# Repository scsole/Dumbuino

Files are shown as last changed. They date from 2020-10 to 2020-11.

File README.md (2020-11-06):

# Dumbuino

A basic Arduino with two 10A 48V DC switches controlled using digital outputs.

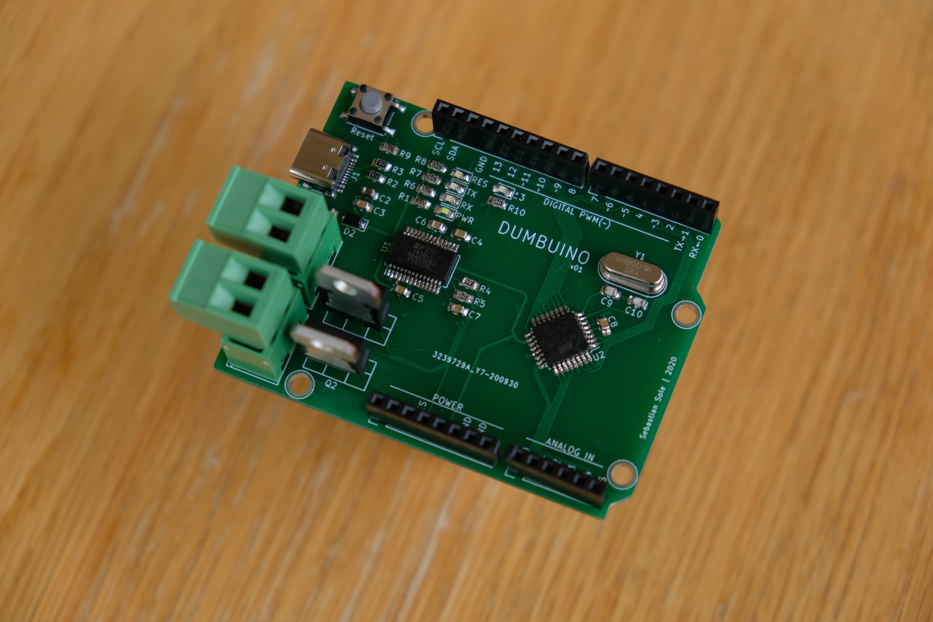
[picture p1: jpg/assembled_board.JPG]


## Specs

| | |
--- | ---
Microcontroller             | ATmega328P
Operating Voltage           | 5V
USB Port                    | USB 2.0 Type-C
10A 48V DC Switches         | 2 (shared with digital pins 9 & 10)
Digital I/O Pins            | 14 (of which 6 provide PWM output)
PWM Digital I/O Pins        | 6
Analog Input Pins           | 6
DC Current per I/O Pin      | 20 mA
DC Current for 3.3V Pin     | 50 mA
Flash Memory                | 32 KB (ATmega328P) of which 0.5 KB used by bootloader
SRAM                        | 2 KB (ATmega328P)
EEPROM                      | 1 KB (ATmega328P)
Clock Speed                 | 16 MHz
LED_BUILTIN                 | 13

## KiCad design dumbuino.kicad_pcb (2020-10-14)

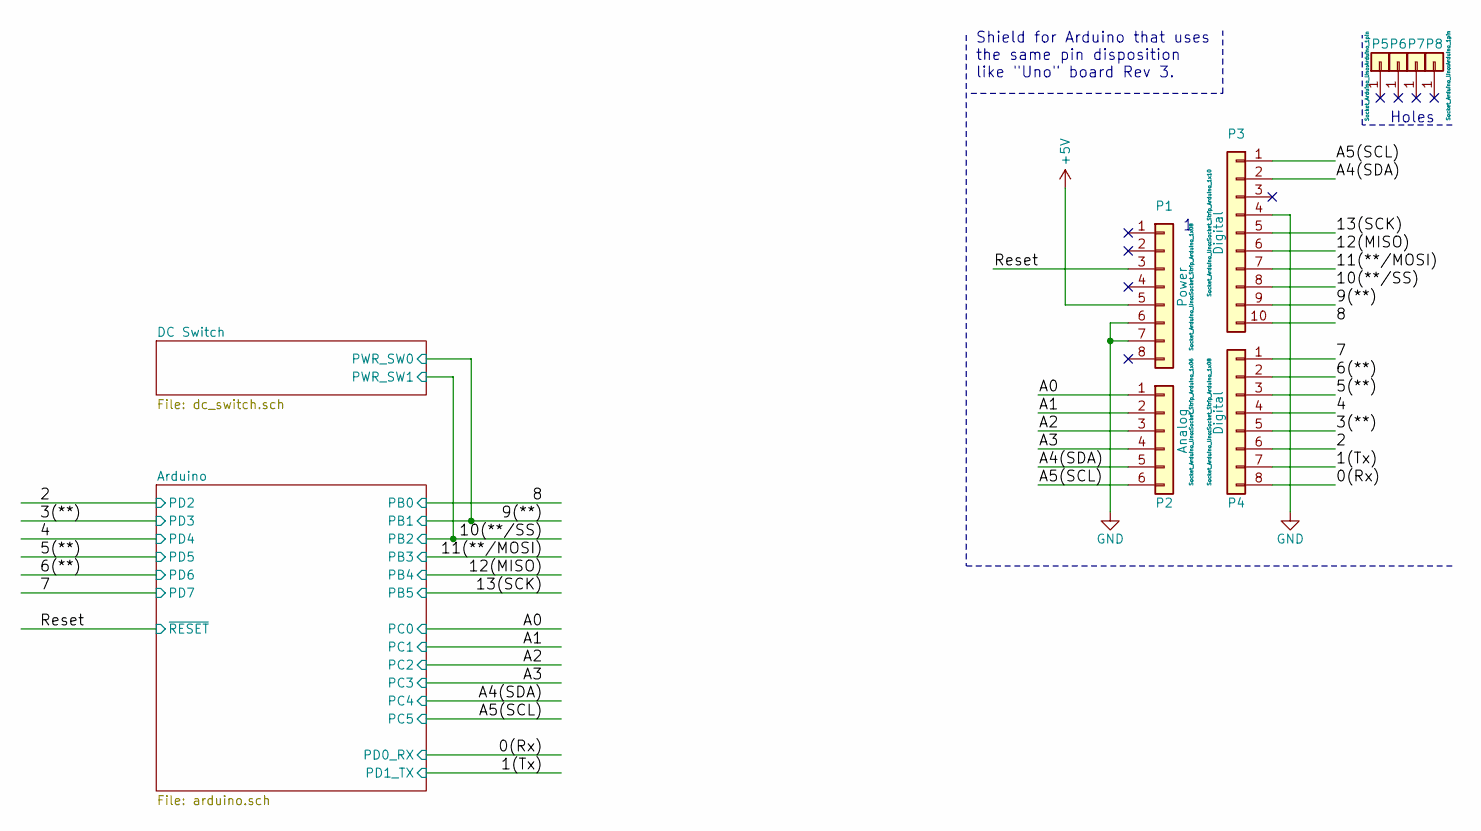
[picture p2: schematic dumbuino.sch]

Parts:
P1: Power; Socket_Strip_Arduino_1x08
P2: Analog; Socket_Strip_Arduino_1x06
P3: Digital; Socket_Strip_Arduino_1x10
P4: Digital; Socket_Strip_Arduino_1x08
P5, P6, P7, P8: CONN_01X01; Arduino_1pin

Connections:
+5V: P1.5; also elsewhere on the board
/0(Rx): P4.8; also elsewhere on the board
/1(Tx): P4.7; also elsewhere on the board
/2: P4.6; also elsewhere on the board
/3(**): P4.5; also elsewhere on the board
/4: P4.4; also elsewhere on the board
/5(**): P4.3; also elsewhere on the board
/6(**): P4.2; also elsewhere on the board
/7: P4.1; also elsewhere on the board
/8: P3.10; also elsewhere on the board
/9(**): P3.9; also elsewhere on the board
/10(**/SS): P3.8; also elsewhere on the board
/11(**/MOSI): P3.7; also elsewhere on the board
/12(MISO): P3.6; also elsewhere on the board
/13(SCK): P3.5; also elsewhere on the board
/A0: P2.1; also elsewhere on the board
/A1: P2.2; also elsewhere on the board
/A2: P2.3; also elsewhere on the board
/A3: P2.4; also elsewhere on the board
/A4(SDA): P2.5, P3.2; also elsewhere on the board
/A5(SCL): P2.6, P3.1; also elsewhere on the board
/Reset: P1.3; also elsewhere on the board
GND: P1.6, P1.7, P3.4; also elsewhere on the board

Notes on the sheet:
Holes
Shield for Arduino that uses the same pin disposition like "Uno" board Rev 3.

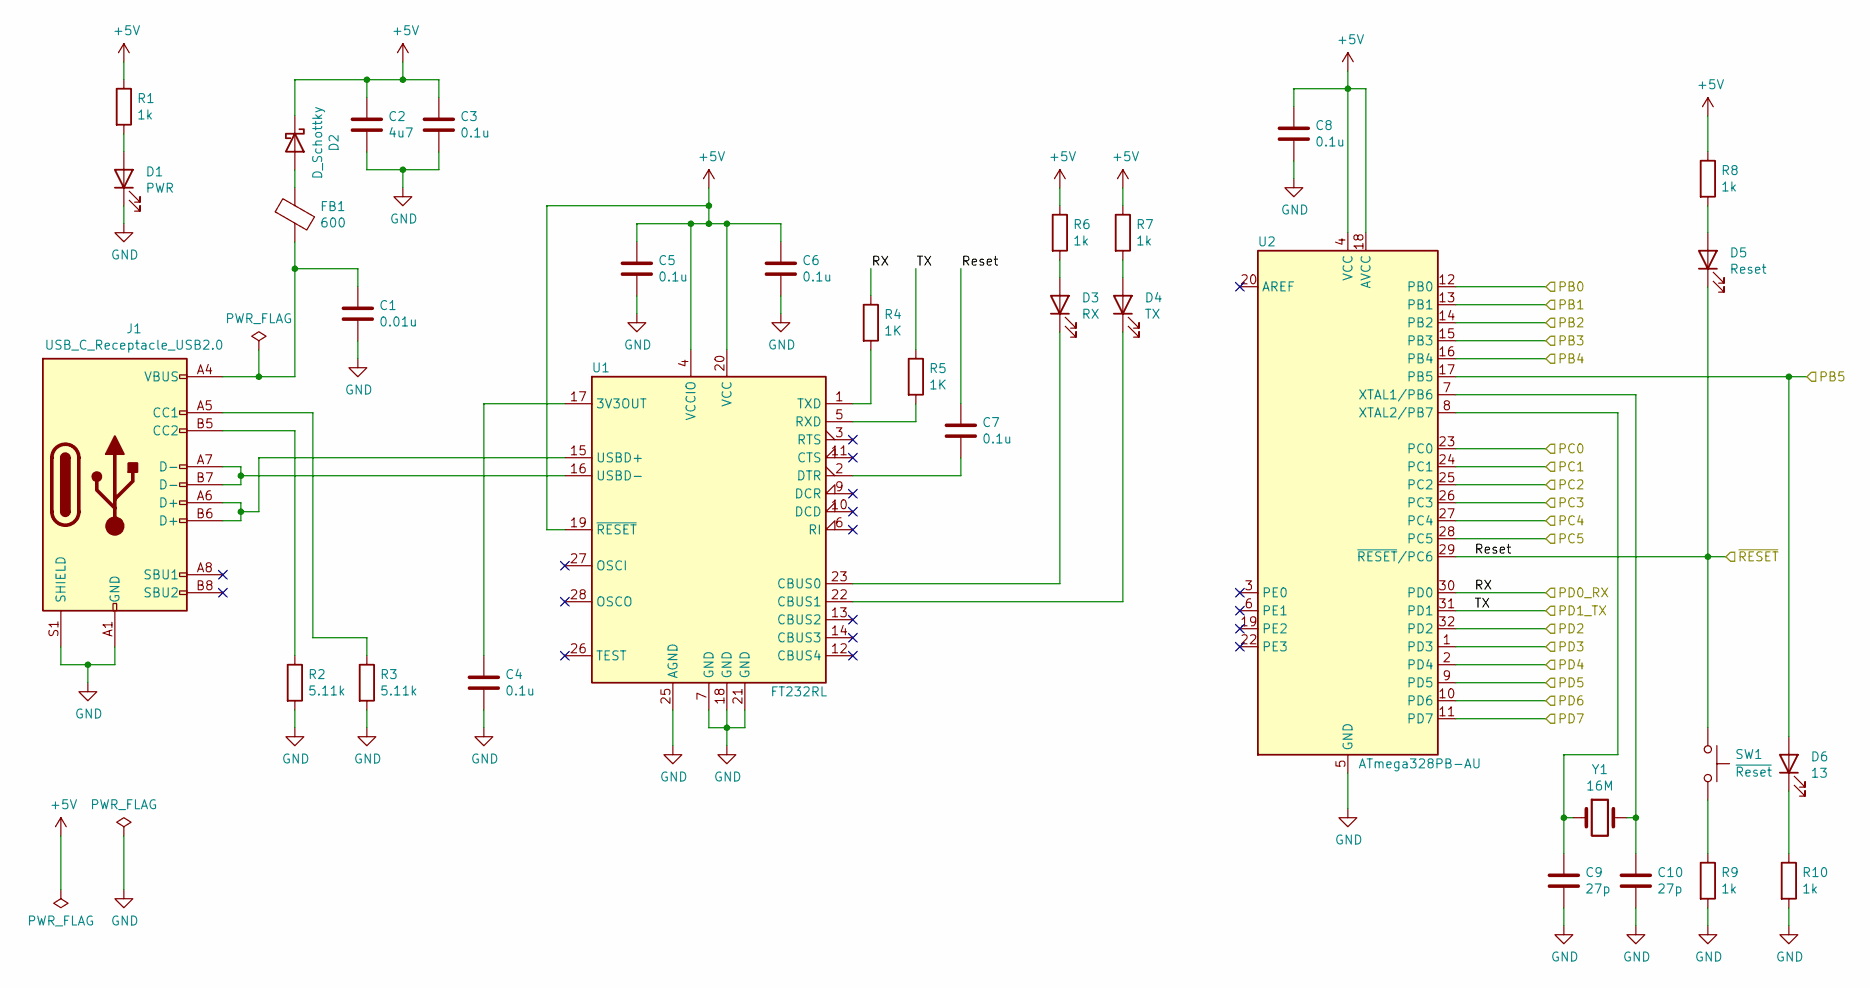
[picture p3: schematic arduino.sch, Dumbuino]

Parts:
C1: 0.01u; C_0805_2012Metric_Pad1.15x1.40mm_HandSolder
C2: 4u7; C_0805_2012Metric_Pad1.15x1.40mm_HandSolder
C3, C4, C5, C6, C7, C8: 0.1u; C_0805_2012Metric_Pad1.15x1.40mm_HandSolder
C9, C10: 27p; C_0805_2012Metric_Pad1.15x1.40mm_HandSolder
D1: PWR; LED_0805_2012Metric_Pad1.15x1.40mm_HandSolder
D2: D_Schottky; D_SOD-123F
D3: RX; LED_0805_2012Metric_Pad1.15x1.40mm_HandSolder
D4: TX; LED_0805_2012Metric_Pad1.15x1.40mm_HandSolder
D5: Reset; LED_0805_2012Metric_Pad1.15x1.40mm_HandSolder
D6: 13; LED_0805_2012Metric_Pad1.15x1.40mm_HandSolder
FB1: 600; L_0805_2012Metric_Pad1.15x1.40mm_HandSolder
J1: USB_C_Receptacle_USB2.0; USB_C_Receptacle_HRO_TYPE-C-31-M-12
R1, R6, R7, R8, R9, R10: 1k; R_0805_2012Metric_Pad1.15x1.40mm_HandSolder
R2, R3: 5.11k; R_0805_2012Metric_Pad1.15x1.40mm_HandSolder
R4, R5: 1K; R_0805_2012Metric_Pad1.15x1.40mm_HandSolder
SW1: ~Reset; SW_SPST_PTS645
U1: FT232RL; SSOP-28_5.3x10.2mm_P0.65mm
U2: ATmega328PB-AU; TQFP-32_7x7mm_P0.8mm
Y1: 16M; Crystal_HC49-U_Vertical

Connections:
+5V: C2.1, C3.1, C5.1, C6.1, C8.1, D2.1 (K), R1.1, R6.1, R7.1, R8.1, U1.4 (VCCIO), U1.19 (~RESET~), U1.20 (VCC), U2.4 (VCC), U2.18 (AVCC); also elsewhere on the board
/0(Rx): R4.1, U2.30 (PD0); also elsewhere on the board
/1(Tx): R5.1, U2.31 (PD1); also elsewhere on the board
/2: U2.32 (PD2); also elsewhere on the board
/3(**): U2.1 (PD3); also elsewhere on the board
/4: U2.2 (PD4); also elsewhere on the board
/5(**): U2.9 (PD5); also elsewhere on the board
/6(**): U2.10 (PD6); also elsewhere on the board
/7: U2.11 (PD7); also elsewhere on the board
/8: U2.12 (PB0); also elsewhere on the board
/9(**): U2.13 (PB1); also elsewhere on the board
/10(**/SS): U2.14 (PB2); also elsewhere on the board
/11(**/MOSI): U2.15 (PB3); also elsewhere on the board
/12(MISO): U2.16 (PB4); also elsewhere on the board
/13(SCK): D6.2 (A), U2.17 (PB5); also elsewhere on the board
/A0: U2.23 (PC0); also elsewhere on the board
/A1: U2.24 (PC1); also elsewhere on the board
/A2: U2.25 (PC2); also elsewhere on the board
/A3: U2.26 (PC3); also elsewhere on the board
/A4(SDA): U2.27 (PC4); also elsewhere on the board
/A5(SCL): U2.28 (PC5); also elsewhere on the board
/Reset: C7.2, D5.1 (K), SW1.1, U2.29 (~RESET~/PC6); also elsewhere on the board
GND: C1.2, C2.2, C3.2, C4.2, C5.2, C6.2, C8.2, C9.2, C10.2, D1.1 (K), J1.A1 (GND), J1.A12 (GND), J1.B1 (GND), J1.B12 (GND), J1.S1 (SHIELD), R2.2, R3.2, R9.2, R10.2, U1.7 (GND), U1.18 (GND), U1.21 (GND), U1.25 (AGND), U2.5 (GND), U2.21 (GND); also elsewhere on the board
unnamed: C1.1, FB1.2, J1.A4 (VBUS), J1.A9 (VBUS), J1.B4 (VBUS), J1.B9 (VBUS)
unnamed: C4.1, U1.17 (3V3OUT)
unnamed: C7.1, U1.2 (DTR)
unnamed: C9.1, U2.8 (XTAL2/PB7), Y1.1
unnamed: C10.1, U2.7 (XTAL1/PB6), Y1.2
unnamed: D1.2 (A), R1.2
unnamed: D2.2 (A), FB1.1
unnamed: D3.1 (K), U1.23 (CBUS0)
unnamed: D3.2 (A), R6.2
unnamed: D4.1 (K), U1.22 (CBUS1)
unnamed: D4.2 (A), R7.2
unnamed: D5.2 (A), R8.2
unnamed: D6.1 (K), R10.1
unnamed: J1.A5 (CC1), R3.1
unnamed: J1.A6 (D+), J1.B6 (D+), U1.15 (USBD+)
unnamed: J1.A7 (D-), J1.B7 (D-), U1.16 (USBD-)
unnamed: J1.B5 (CC2), R2.1
unnamed: R4.2, U1.1 (TXD)
unnamed: R5.2, U1.5 (RXD)
unnamed: R9.1, SW1.2

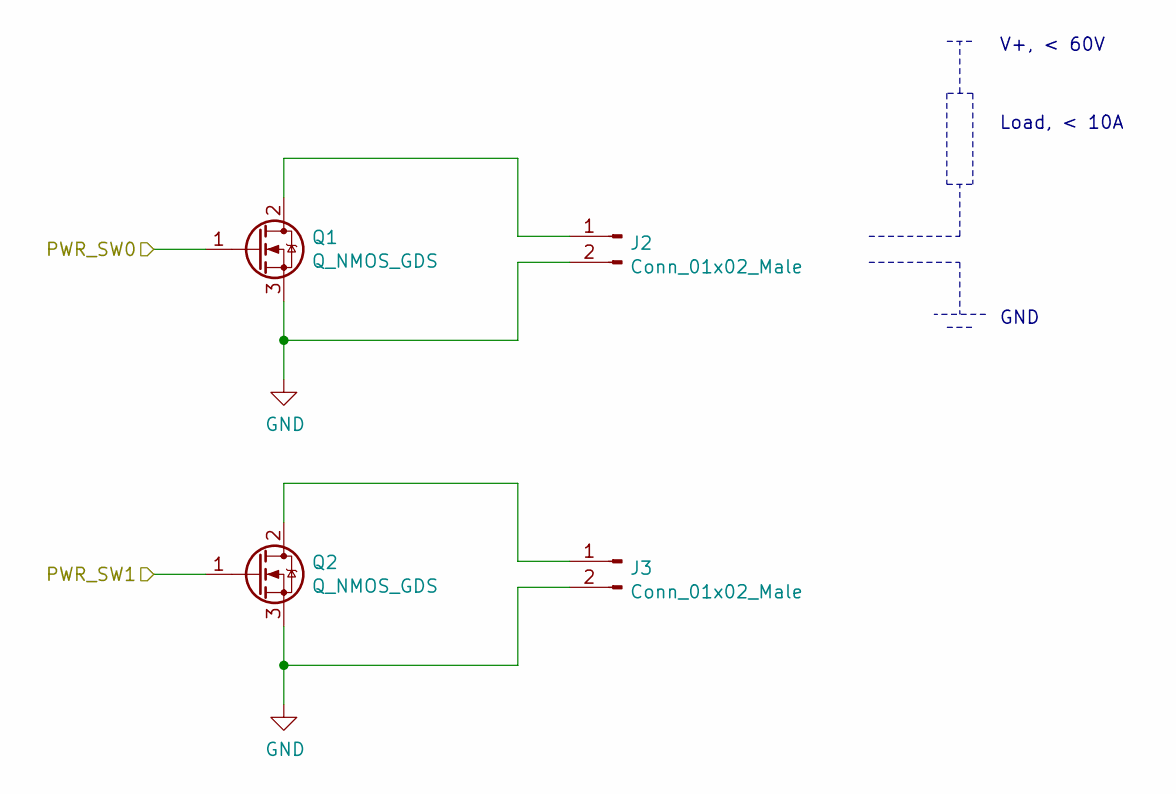
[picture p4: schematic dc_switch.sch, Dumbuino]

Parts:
J2, J3: Conn_01x02_Male; PhoenixContact_MSTBVA_2,5_2-G-5,08_1x02_P5.08mm_Vertical
Q1, Q2: Q_NMOS_GDS; TO-220F-3_Vertical

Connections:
/9(**): Q1.1 (G); also elsewhere on the board
/10(**/SS): Q2.1 (G); also elsewhere on the board
GND: J2.2, J3.2, Q1.3 (S), Q2.3 (S); also elsewhere on the board
unnamed: J2.1, Q1.2 (D)
unnamed: J3.1, Q2.2 (D)

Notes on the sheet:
GND
Load, < 10A
V+, < 60V

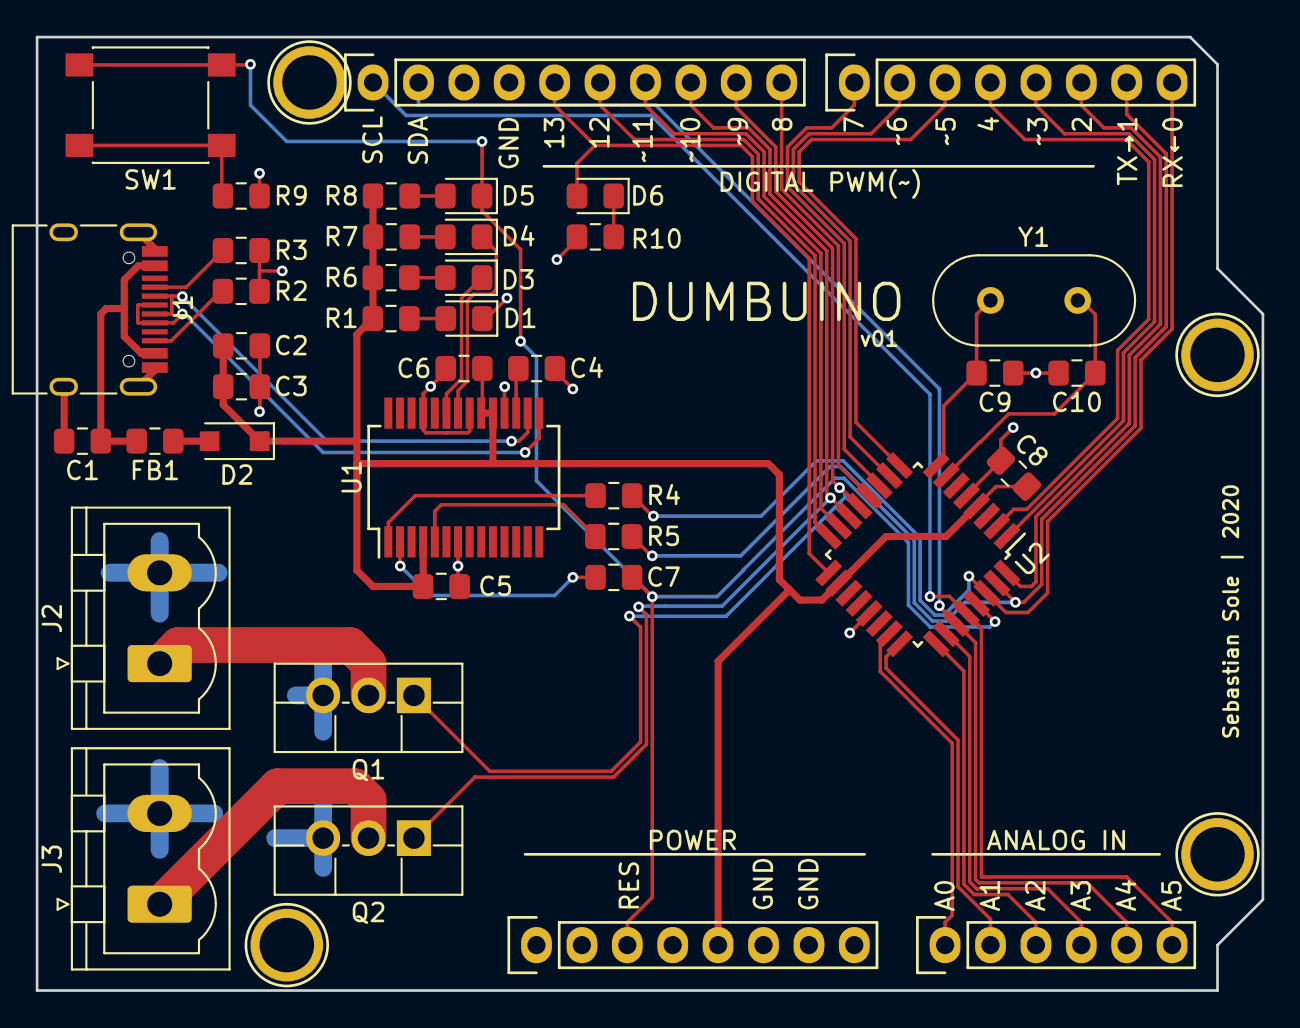
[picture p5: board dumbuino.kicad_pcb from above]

Board: 4 copper layers, 68.6 x 53.3 mm, 44 parts (0 on the bottom side), 45 nets.

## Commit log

2020-09-20 Initial template files
    [dumbuino.kicad_pcb, dumbuino.sch]
2020-09-20 Added arduino schematic
    [arduino.sch, dumbuino.sch]
2020-09-20 Added two 48V digital outputs
    [arduino.sch, dc_switch.sch, dumbuino.sch]
2020-09-20 Associated footprints
    [arduino.sch, dc_switch.sch]
2020-09-20 Defined board properties
    [dumbuino.kicad_pcb]
2020-09-20 Initial component placement
    [dumbuino.kicad_pcb]
2020-09-20 Finished initial board layout
    [dumbuino.kicad_pcb]
2020-09-20 Adjusted tracks
    [dumbuino.kicad_pcb]
2020-09-20 Updated F.SilkS
    [dumbuino.kicad_pcb]
2020-09-23 Update track width
    [dumbuino.kicad_pcb]
2020-09-23 Generated gerbers
    [dumbuino-B_Cu.gbr, dumbuino-B_Mask.gbr, dumbuino-B_SilkS.gbr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]
2020-10-14 Updated values
    [arduino.sch, dumbuino.kicad_pcb]
